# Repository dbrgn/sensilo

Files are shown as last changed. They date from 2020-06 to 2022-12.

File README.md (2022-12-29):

# sensilo

A generic BLE sensor node based on the nRF52832. Firmware written in Rust with the RTIC framework.

Current status: Obsolete, replaced by [sensilo-v2](https://github.com/dbrgn/sensilo-v2).

## Project Name

"Sensilo" is the [Esperanto word for "sensor"](https://en.bab.la/dictionary/esperanto-english/sensilo).

## Components

- [Firmware](./firmware/)
- [Gateway](./gateway/)
- [Hardware](./hardware/)

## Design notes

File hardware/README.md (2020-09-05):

# Sensilo

Sensilo sensor node PCB.

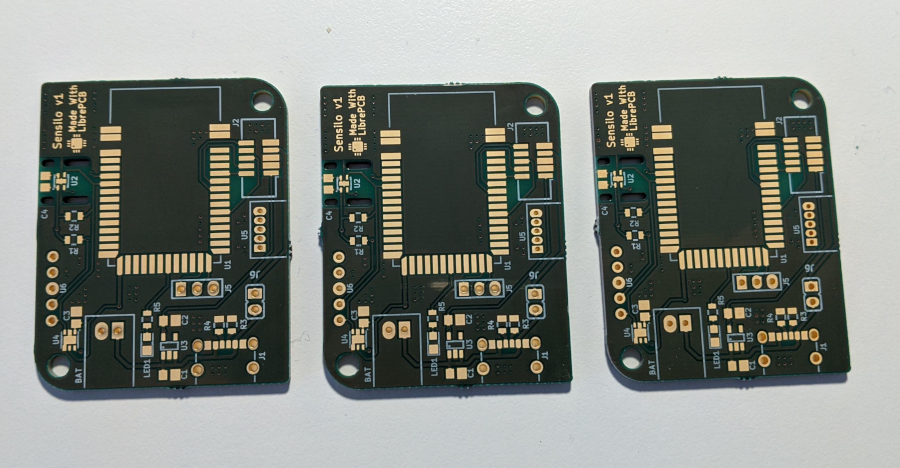
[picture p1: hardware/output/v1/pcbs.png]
PCBs


## Editing

This is a [LibrePCB](https://librepcb.org) project!

## License

© 2020 Danilo Bargen. Licensed under the TAPR Open Hardware License
(www.tapr.org/OHL).

If you make any modification to this board, it would be great if you could let
me know at mail@dbrgn.ch.

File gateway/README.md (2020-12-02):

# Sensilo Gateway

Rust daemon that receives Sensilo advertisement frames (aka beacons) via
Bluetooth (through libpcap) and processes them.

Measurements are sent to an InfluxDB server.

## Setup

Ensure that the bluetooth adapter is powered on and in scan mode:

    bluetoothctl power on
    bluetoothctl scan on

Then run the daemon with the necessary permissions.

## Config

The daemon requires a config file called `config.toml`. Example:

```toml
[influxdb]
connection_string = "https://influxdb.example.com"
user = "influxuser"
pass = "influxpass"
db = "sensilo"

[[devices]]
name = "Sensilo1"
hex_addr = "864fe067997a"
location = "Kitchen"

[[devices]]
name = "Sensilo2"
hex_addr = "864fe067997b"
```

## Logging

To see the log output:

    export RUST_LOG=sensilo_gateway=debug

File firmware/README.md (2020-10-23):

# Sensilo Node Firmware

Firmware uses the RTIC embedded concurrency framework.

## Tasks

The following tasks make up a measurement cycle:

    +----+    +-----------------+        +-------------------+
    |init| -> |start_measurement| -(t)-> |collect_measurement|
    +----+    +-----------------+        +-------------------+
                                                      |
                                                      v
                                        +----------------+
                                    +-- |broadcast_beacon|
                                    |   +----------------+
                                    |        ^    |
                                    |        |    |
                                    +--(b)---+    |
                                                  v
                                          +----------+
                                          |power_down|
                                          +----------+
Delays:

- `t`: Max measurement duration for the sensor used
- `b`: BEACON_BURST_INTERVAL_MS

## Packet Format

Data is broadcasted in an unconnectable BLE advertisement frame (aka beacon).
The advertising data contains the device name ("Sensilo") as well as a
manufacturer specific entry (Company ID `0xff`) with the actual payload.

The payload starts with a 16 bit counter (starting at 0, incremented for every
beacon burst), followed by measurement entries.

Every measurement entry starts with a single-byte type flag (e.g. `0x01` for a
temperature measurement) followed by a type-specific payload.

All multi-byte values are in little endian byte order.

## Measurement Types

| Type | Description | Value Encoding |
|---|---|---|
| 0x01 | Temperature | Millidegrees Celsius (i32) |
| 0x02 | Relative Humidity | Millipercent (i32) |
| 0x03 | Particulate Matter | TBD |
| 0x04 | Ambient Light | Lux (f32) |

## Development

### Unlocking

When receiving a new board (e.g. the E73-TBB), the nRF often needs to be
unlocked before being able to connect to it with the debugger.

Instructions: https://blog.dbrgn.ch/2020/5/16/nrf52-unprotect-flash-jlink-openocd/

### Flashing (cargo-embed)

Install cargo-embed:

    $ cargo install -f cargo-embed

Flash and reset the target:

    $ cargo embed flash --release

Flash and reset, then show RTT console:

    $ cargo embed flashrtt --release

Only show RTT console:

    $ cargo embed rtt --release

### Flashing (openocd)

Run OpenOCD:

    $ ./openocd.sh

Run the code

    $ cargo run [--release]

### Flashing (J-Link GDB Server)

Run JLinkGDBServer:

    $ ./jlinkgdbserver.sh

Run the code

    $ cargo run [--release]

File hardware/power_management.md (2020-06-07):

# Power Management

## Supply Voltage

Input voltages:

- USB: 4.8-5.2V
- Battery: 2-3V

Sensor supply voltages:

- E73/nRF52832 (SoC): 1.8-3.6V
- SHTC3 (Temp/Humi): 1.62-3.6V
- VEML7700 (Lux): 2.5–3.6V
- SPS30 (PM): 4.5-5.5V

## Non-Mobile

- Power supply 5V via USB C
- LDO for conversion to 3.3V

## Mobile

- Powered by 3V button cell (may reach 2V when empty)

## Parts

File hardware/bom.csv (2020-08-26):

name | count | digikey
Lipo Charger | 2 | 1528-4410-ND

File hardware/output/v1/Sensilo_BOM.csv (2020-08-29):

Quantity | Designators | Value | Device | Package | MANUFACTURER | PARTNUMBER | DIGIKEY
1 | BAT | S2B-XH-A | S2B-XH-A | JST_S2B-XH-A | JST | S2B-XH-A | 455-2257-ND
2 | C1, C2 | 1μF | C-0805 | C-0805 | Samsung | CL21B105KOFNNNG | 1276-6471-1-ND
2 | C3, C4 | 100nF | C-0805 | C-0805 | Samsung | CL21B104KACNNNC | 1276-1099-1-ND
1 | J1 | UJC-HP-3-SMT-TR | UJC-HP-3-SMT-TR | CUI_UJC-HP-3-SMT-TR | CUI Devices | UJC-HP-3-SMT-TR | 2223-UJC-HP-3-SMT-CT-ND
1 | J2 | SWD Connector 3220-10-0300-00 | CNC Tech 3220-10-0300 | CNCTECH_3220-10-0300-XX | CNC Tech | 3220-10-0300-00 | 1175-1629-ND
1 | J5 | UART | Soldered Wire Connector 2.54mm 1x03 ⌀1.0mm | Soldered Wire Connector 1x03 ⌀1.0mm | Sullins | PPTC031LFBN-RC | S7001-ND
1 | J6 |  | Generic Pin Header 2.54mm 1x02 ⌀1.0mm | Pin Header 2.54mm 1x02 ⌀1.0mm | Adam Tech | PH1-02-UA | 2057-PH1-02-UA-ND
1 | LED1 | R 2V 2.8mA | OSRAM LS R976-NR-1 | OSRAM CHIPLED 0805 Diffused | Osram | LS R976-NR-1 | 475-1278-1-ND
1 | R1 | 10kΩ | Resistor 2012 (0805) | RESC2012 (0805) | Yageo | RC0805JR-0710KL | 311-10KARCT-ND
1 | R2 | 10kΩ | Resistor 2012 (0805) | RESC2012 (0805) | Yageo | RC0805JR-0710KL
2 | R3, R4 | 5.1kΩ | Resistor 2012 (0805) | RESC2012 (0805) | Yageo | RC0805JR-075K1L | 311-5.1KARCT-ND
1 | R5 | 470Ω | Resistor 2012 (0805) | RESC2012 (0805) | Yageo | RC0805JR-07470RL | 311-470ARCT-ND
1 | U1 | E73-2G4M04S1B | E73-2G4M04S1B | EBYTE_E73-2G4M04S1[AB] | Ebyte | E73-2G4M04S1B
1 | U2 | SHTC3 | SHTC3 | Sensirion SHTCx | Sensirion | SHTC3 | 1649-1100-1-ND
1 | U3 | TPS7A0333PDBVR 200mA | TPS7A0333PDBVx | SOT95P280X145-5 | Texas Instruments | TPS7A0333PDBVR | 296-TPS7A0333PDBVRCT-ND
1 | U4 | SGP40 | SGP30 | SENSIRION_SGPxx | Sensirion | SGP40
1 | U5 | SPS30 (JST S5B-ZR) | SPS30 JST ZH | JST_S5B-ZR | JST | S5B-ZR(LF)(SN) | 455-1672-ND
1 | U6 | Adafruit VEML7700 Breakout (Socket strip 1x5) | Adafruit VEML7700 Breakout | Adafruit VEML7700 Breakout | Sullins | PPTC051LFBN-RC | S6103-ND

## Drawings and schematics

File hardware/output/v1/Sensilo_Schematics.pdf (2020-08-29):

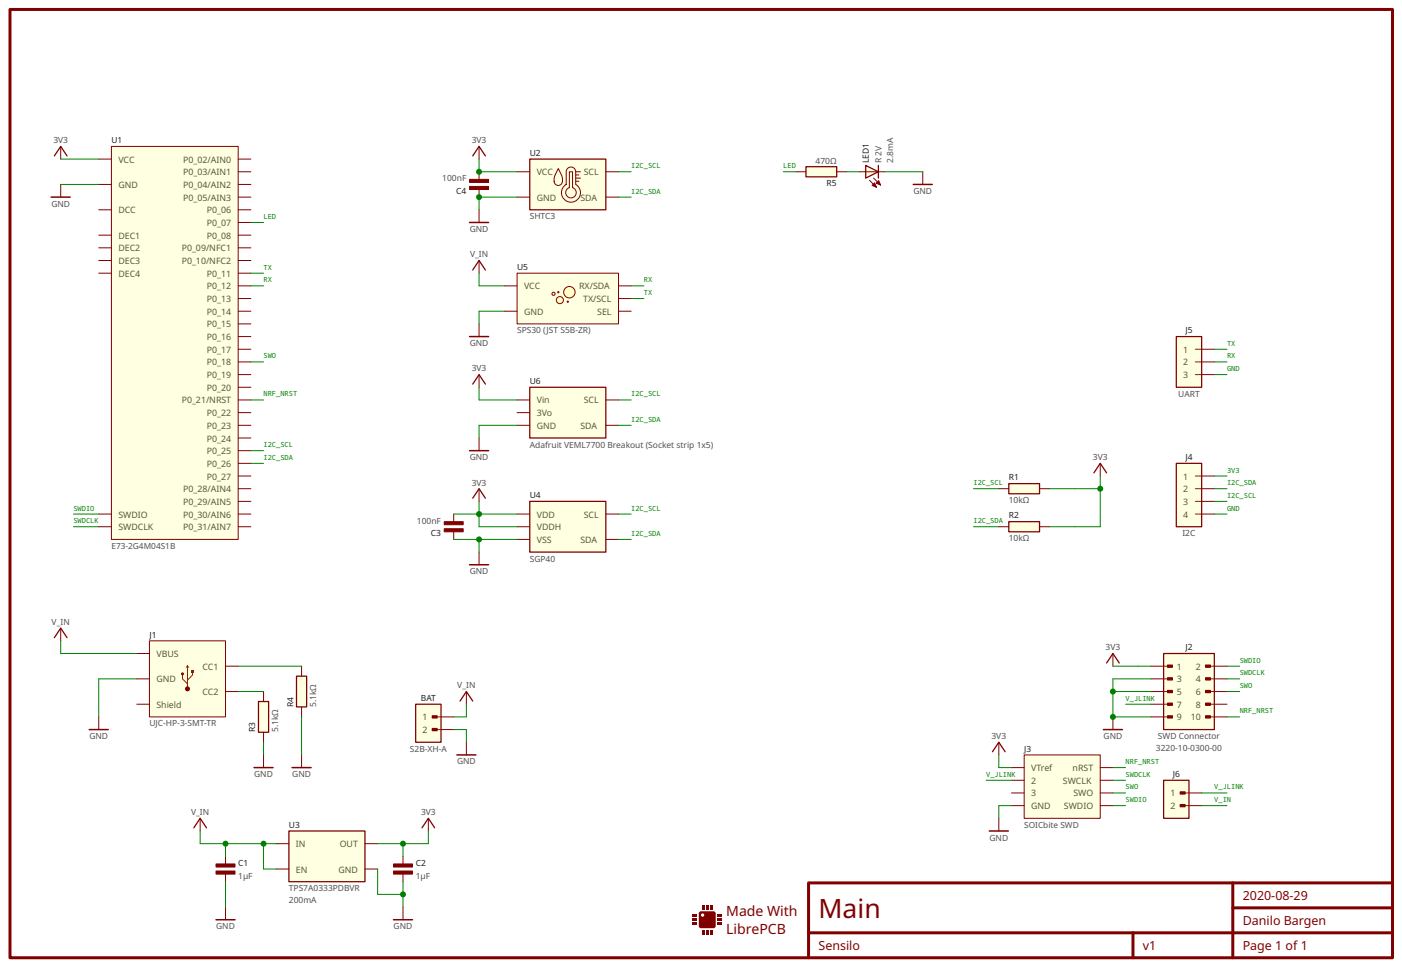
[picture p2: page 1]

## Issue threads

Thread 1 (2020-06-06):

Packet structure

dbrgn, 2020-06-06:
The current prototype simply re-broadcasts the measurements twice a second. We should have a different packet structure.

- Add a counter for deduplication
- Keep the packet type byte
- Encrypt data (?)

dbrgn, 2020-06-06:
Let's use simple type-value encoding:

    | counter | type1 | value1 | type2 | value2 | ...

- Counter: 16 bit unsigned integer, may overflow
- Type: 1 byte
- Value: Depends on type, usually fixed-size

The type and value could also be compressed (e.g. by using only 4 bits for the type), but that's probably overkill.

Closed 2020-06-06.

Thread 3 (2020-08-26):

PCB: Double-check battery connector

dbrgn, 2020-08-26:
Is the polarity correct?

Closed 2020-08-26.

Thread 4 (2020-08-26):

Hardware: Add SPS30 connector

dbrgn, 2020-08-26:

dbrgn, 2020-08-26:
Fixed!

Closed 2020-08-26.

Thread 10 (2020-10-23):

Hardware: Put VEML7700 directly on PCB

dbrgn, 2020-10-23:
https://www.digikey.ch/product-detail/de/vishay-semiconductor-opto-division/VEML7700-TR/VEML7700CT-ND/5820244

The Adafruit module adds a regulator, which isn't necessary.

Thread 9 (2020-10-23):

Hardware: Replace XH battery connector with SH

dbrgn, 2020-10-23:
The batteries I received have the wrong connector.

However, SH is better than XH, pitch is 1mm instead of 2.5mm, so they're much smaller.

dbrgn, 2020-10-23:
Replace with https://www.digikey.ch/products/de?keywords=530480210 (Molex PicoBlaze 530480210)

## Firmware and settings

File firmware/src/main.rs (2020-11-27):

#![no_main]
#![cfg_attr(not(test), no_std)]

// Panic handler
use panic_persist::get_panic_message_utf8;

use core::cmp::max;

use nrf52832_hal::{self as hal, pac, prelude::*};
use rtic::app;
use rtt_target::{rprintln, rtt_init_print};
use rubble::{
    beacon::Beacon,
    link::{ad_structure::AdStructure, DeviceAddress, MIN_PDU_BUF},
};
use rubble_nrf5x::{
    radio::{BleRadio, PacketBuffer},
    utils::get_device_address,
};
use shared_bus_rtic::SharedBus;
use shtcx::{shtc3, ShtC3};
use veml6030::Veml6030;

mod monotonic_nrf52;

use monotonic_nrf52::{Instant, U32Ext};

// Measure at a specific interval
const MEASURE_INTERVAL_MS: u32 = 3000;

// Send 5 beacons, spaced 20 ms apart
const BEACON_BURST_COUNT: u8 = 5;
const BEACON_BURST_INTERVAL_MS: u32 = 20;

// Sensor types
const SENSOR_TEMP: u8 = 0x01;
const SENSOR_HUMI: u8 = 0x02;
const SENSOR_LUX: u8 = 0x04;

// BLE Beacon
const AD_STRUCTURE_MANUFACTURER_DATA: u8 = 0xff;

// VEML sensor integration time
const VEML_INTEGRATION_TIME: veml6030::IntegrationTime = veml6030::IntegrationTime::Ms25;

pub struct SharedBusResources<T: 'static> {
    sht: ShtC3<SharedBus<T>>,
    veml: Veml6030<SharedBus<T>>,
}

type SharedBusType = hal::twim::Twim<pac::TWIM0>;

#[app(device = crate::pac, peripherals = true, monotonic = crate::monotonic_nrf52::Tim1)]
const APP: () = {
    struct Resources {
        // LED
        led: hal::gpio::p0::P0_07<hal::gpio::Output<hal::gpio::PushPull>>,

        // BLE
        #[init([0; MIN_PDU_BUF])]
        ble_tx_buf: PacketBuffer,
        #[init([0; MIN_PDU_BUF])]
        ble_rx_buf: PacketBuffer,
        radio: BleRadio,
        device_address: DeviceAddress,

        // I²C devices
        i2c: SharedBusResources<SharedBusType>,

        // Measurements
        #[init(None)]
        measurement_start: Option<Instant>,

        // Beacon
        #[init(None)]
        beacon: Option<Beacon>,
    }

    #[init(resources = [ble_tx_buf, ble_rx_buf], spawn = [start_measurement])]
    fn init(ctx: init::Context) -> init::LateResources {
        // Init RTT
        rtt_init_print!();
        rprintln!("Initializing…");

        // Check for existing crash dumps
        if let Some(msg) = get_panic_message_utf8() {
            rprintln!("Found a crash dump:\n--- START OF CRASH---\n{}\n--- END OF CRASH ---", msg.trim());
        }

        // Destructure device peripherals
        let pac::Peripherals {
            CLOCK,
            FICR,
            P0,
            RADIO,
            TIMER1,
            TWIM0,
            ..
        } = ctx.device;

        // Set up clocks. On reset, the high frequency clock is already used,
        // but we also need to switch to the external HF oscillator. This is
        // needed for Bluetooth to work.
        let _clocks = hal::clocks::Clocks::new(CLOCK).enable_ext_hfosc();

        // Set up GPIO peripheral
        let gpio = hal::gpio::p0::Parts::new(P0);

        // Initialize monotonic timer on TIMER1 (for RTIC)
        monotonic_nrf52::Tim1::initialize(TIMER1);

        // Initialize LED pin
        // TODO: LED wrapper that knows whether low power mode is enabled
        let led = gpio.p0_07.into_push_pull_output(hal::gpio::Level::High);

        // Initialize TWIM (I²C) peripheral
        let sda = gpio.p0_26.into_floating_input().degrade();
        let scl = gpio.p0_25.into_floating_input().degrade();
        let twim = hal::twim::Twim::new(
            TWIM0,
            hal::twim::Pins { sda, scl },
            hal::twim::Frequency::K250,
        );

        // Create shared bus
        let bus_manager = shared_bus_rtic::new!(twim, SharedBusType);

        // Initialize SHT sensor
        let mut sht = shtc3(bus_manager.acquire());
        rprintln!(
            "SHTC3: Device identifier is {}",
            sht.device_identifier().unwrap()
        );

        // Initialize VEML7700 lux sensor
        let mut veml = Veml6030::new(bus_manager.acquire(), veml6030::SlaveAddr::default());
        if let Err(e) = veml.set_gain(veml6030::Gain::OneQuarter) {
            rprintln!("VEML7700: Could not set gain: {:?}", e);
        }
        if let Err(e) = veml.set_integration_time(VEML_INTEGRATION_TIME) {
            rprintln!("VEML7700: Could not set gain: {:?}", e);
        }

        // Get bluetooth device address
        let device_address = get_device_address();
        rprintln!("Bluetooth device address: {:?}", device_address);

        // Initialize radio
        let radio = BleRadio::new(
            RADIO,
            &FICR,
            ctx.resources.ble_tx_buf,
            ctx.resources.ble_rx_buf,
        );

        // Schedule measurement immediately
        ctx.spawn.start_measurement().unwrap();

        rprintln!("Init done");
        init::LateResources {
            radio,
            device_address,
            i2c: SharedBusResources { sht, veml },
            led,
        }
    }

    #[idle]
    fn idle(_ctx: idle::Context) -> ! {
        // It seems that the HFCLK is stopped in standby mode (entered through WFE/WFI).
        // This prevents the monotonic timer from working. To avoid this issue, don't go into sleep
        // mode in idle, but instead do busy-looping for now.
        loop {
            cortex_m::asm::nop();
        }
    }

    /// Start a measurement
    #[task(resources = [i2c, measurement_start], schedule = [collect_measurement])]
    fn start_measurement(ctx: start_measurement::Context) {
        let i2c = ctx.resources.i2c;
        let power_mode = shtcx::PowerMode::NormalMode;

        // Store the instant when this task was scheduled.
        // This ensures that there is no jitter in scheduling.
        *ctx.resources.measurement_start = Some(ctx.scheduled);

        // Trigger SHTC3 measurement
        i2c.sht.start_measurement(power_mode).unwrap();
        let sht_delta_us: u32 = shtcx::max_measurement_duration(&i2c.sht, power_mode) as u32;

        // Turn on VEML7700
        //
        // Note: After enabling the sensor, a startup time of 4 ms plus the integration time must
        // be awaited.
        if let Err(e) = i2c.veml.enable() {
            rprintln!("VEML7700: Could not enable sensor: {:?}", e);
        }
        let veml_delta_us: u32 = VEML_INTEGRATION_TIME.as_us() + 4_000;

        // Calculate timedelta until collection
        let timedelta = max(sht_delta_us, veml_delta_us).micros();

        // Schedule measurement collection
        ctx.schedule
            .collect_measurement(Instant::now() + timedelta)
            .unwrap();
    }

    /// Collect a measurement. Then send the data using non-connectable BLE
    /// advertisement frames (beacons).
    #[task(
        resources = [i2c, measurement_start, device_address, beacon],
        schedule = [start_measurement],
        spawn = [broadcast_beacon],
    )]
    fn collect_measurement(ctx: collect_measurement::Context) {
        static mut COUNTER: u16 = 0;

        let i2c = ctx.resources.i2c;

        // Take measurement start time
        let measurement_start = ctx
            .resources
            .measurement_start
            .take()
            .expect("Cannot collect measurement without starting a measurement first");

        // Collect SHTC3 measurement result
        let sht_measurement = i2c.sht.get_measurement_result().unwrap();
        rprintln!(
            "SHTC3 measurement: {}°C / {} %RH",
            sht_measurement.temperature.as_degrees_celsius(),
            sht_measurement.humidity.as_percent()
        );

        // Collect VEML7700 measurement result
        let veml_measurement = match i2c.veml.read_lux() {
            Ok(lux) => {
                rprintln!("VEML7700 measurement: {:.1} lx", lux);
                Some(lux)
            }
            Err(e) => {
                rprintln!("VEML7700: Could not measure lux: {:?}", e);
                None
            }
        };
        if let Err(e) = i2c.veml.disable() {
            rprintln!("VEML7700: Could not shut down: {:?}", e);
        }

        // Prepare beacon payload
        let temp = sht_measurement
            .temperature
            .as_millidegrees_celsius()
            .to_le_bytes();
        let humi = sht_measurement.humidity.as_millipercent().to_le_bytes();
        let lux = veml_measurement
            .expect("TODO: Allow VEML measurement errors")
            .to_le_bytes();
        let counter_bytes = COUNTER.to_le_bytes();
        #[rustfmt::skip]
        let payload = [
            0xff, 0xff,
            counter_bytes[0], counter_bytes[1],
            SENSOR_TEMP, temp[0], temp[1], temp[2], temp[3], // i32 LE
            SENSOR_HUMI, humi[0], humi[1], humi[2], humi[3], // i32 LE
            SENSOR_LUX, lux[0], lux[1], lux[2], lux[3], // f32 LE
        ];

        // Create beacon
        let advertisement_data = [
            AdStructure::CompleteLocalName("Sensilo"),
            AdStructure::Unknown {
                ty: AD_STRUCTURE_MANUFACTURER_DATA,
                data: &payload,
            },
        ];
        let beacon = Beacon::new(*ctx.resources.device_address, &advertisement_data)
            .expect("Could not create beacon");
        *ctx.resources.beacon = Some(beacon);
        rprintln!("Created beacon with counter {}", COUNTER);

        // Broadcast beacon
        if ctx.spawn.broadcast_beacon(0).is_err() {
            rprintln!("Error: Could not spawn broadcast_beacon");
        }

        // Increment counter (allow wrap-around)
        *COUNTER = COUNTER.wrapping_add(1);

        // Schedule a new measurement
        ctx.schedule
            .start_measurement(measurement_start + MEASURE_INTERVAL_MS.millis())
            .unwrap();
    }

    /// Broadcast the beacon until the BEACON_BURST_COUNT has been reached.
    #[task(resources = [radio, beacon, led], schedule = [broadcast_beacon])]
    fn broadcast_beacon(ctx: broadcast_beacon::Context, i: u8) {
        if i == 0 {
            ctx.resources.led.set_low().ok();
        } else if i >= BEACON_BURST_COUNT {
            ctx.resources.led.set_high().ok();
            return;
        }

        if let Some(beacon) = ctx.resources.beacon {
            beacon.broadcast(ctx.resources.radio);
            rprintln!("Sent beacon");

            if ctx
                .schedule
                .broadcast_beacon(ctx.scheduled + BEACON_BURST_INTERVAL_MS.millis(), i + 1)
                .is_err()
            {
                rprintln!("Error: Could not re-schedule broadcast_beacon");
            }
        } else {
            rprintln!("Error: No beacon that can be broadcasted");
        }
    }

    // Provide unused interrupts to RTIC for its scheduling
    extern "C" {
        fn SWI0_EGU0();
        fn SWI1_EGU1();
        fn SWI2_EGU2();
        fn SWI3_EGU3();
        fn SWI4_EGU4();
        fn SWI5_EGU5();
    }
};

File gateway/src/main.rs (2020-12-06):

use std::collections::HashMap;

use futures::StreamExt;
use hci::protocol::{
    BasicDataType_Data, HciEvent_Event, HciMessage, HciMessage_Message, LeMetaEvent_Event,
};
use lru::LruCache;
use pcap_async::{Config, Handle, Packet, PacketStream};

mod config;
mod influxdb;
mod measurement;
mod types;

use measurement::MeasurementBuilder;
use types::Address;

// Store a LRU cache with the last `DEDUPLICATION_LRU_SIZE` counters for every address.
// If a counter value is contained in the cache, ignore the message.
const DEDUPLICATION_LRU_SIZE: usize = 5;
type DeduplicationCache = HashMap<Address, LruCache<u16, ()>>;

fn print_usage(args: &[String]) {
    println!("Sensilo Gateway\n");
    println!("Usage: {} [-h|--help] [CONFIGFILE]", args[0]);
}

fn main() -> anyhow::Result<()> {
    env_logger::init();

    // Parse args
    let args: Vec<String> = std::env::args().collect();
    if args.iter().any(|arg| arg == "-h" || arg == "--help") {
        print_usage(&args);
        std::process::exit(0);
    }
    if args.len() > 2 {
        print_usage(&args);
        std::process::exit(1);
    }

    println!("Sensilo Gateway\n");

    // Parse config
    let configfile = args.iter().nth(1).map(|s| &**s).unwrap_or("config.toml");
    println!("Loading config from {}...", configfile);
    let config: config::Config = toml::from_str(&std::fs::read_to_string(configfile)?)?;
    let addresses: Vec<Address> = config
        .devices
        .iter()
        .map(|dev| Address::from_hex(&dev.hex_addr))
        .collect();

    println!("Available bluetooth capture interfaces:");
    for iface in pcap_async::Info::all().expect("Could not get list of interfaces") {
        if iface.name.contains("blue") || iface.name.contains("ble") {
            println!("  - {}", iface.name);
            for ip in iface.ips {
                println!("    - {}", ip);
            }
        }
    }

    println!("Listening for beacons from the following devices:");
    for dev in &config.devices {
        if let Some(ref location) = dev.location {
            println!("  - [{}] {} ({})", dev.hex_addr, dev.name, location);
        } else {
            println!("  - [{}] {}", dev.hex_addr, dev.name);
        }
    }

    // Create HTTP client
    let agent = influxdb::make_ureq_agent();

    println!();
    smol::block_on(async {
        println!("Opening device bluetooth0...");
        let handle = Handle::live_capture("bluetooth0").expect("No handle created");
        //let handle = Handle::file_capture("/tmp/ble.pcap").expect("No handle created");

        let mut pcap_config = Config::default();
        pcap_config.with_blocking(true);

        let mut stream = PacketStream::new(pcap_config, std::sync::Arc::clone(&handle))
            .expect("Failed to build");

        let mut deduplication_cache: DeduplicationCache = HashMap::new();
        while let Some(packets_result) = stream.next().await {
            if let Ok(packets) = packets_result {
                for packet in packets {
                    log::trace!("{:?}", packet);
                    // TODO: Non-await?
                    let _ = process_packet(
                        packet,
                        &mut deduplication_cache,
                        &config,
                        &addresses,
                        agent.clone(),
                    )
                    .await;
                }
            } else {
                println!("Error: {:?}", packets_result);
            }
        }

        Ok(())
    })
}

async fn process_packet(
    packet: Packet,
    deduplication_cache: &mut DeduplicationCache,
    config: &config::Config,
    addresses: &[Address],
    agent: ureq::Agent,
) -> Option<()> {
    // Validate length
    if packet.original_length() != packet.actual_length() {
        log::debug!(
            "Invalid packet length: {} != {}",
            packet.original_length(),
            packet.actual_length()
        );
        return None;
    }

    // Try to parse HCI message
    let payload = &packet.data()[4..];
    let parsed = HciMessage::parse(payload)
        .map_err(|e| {
            log::debug!("Could not parse HCI message");
            e
        })
        .ok()?;

    if !parsed.0.is_empty() {
        log::debug!("Payload parsed incompletely");
        return None;
    }

    // Extract event
    let event = if let HciMessage_Message::HciEvent(val) = parsed.1.get_message() {
        val
    } else {
        log::trace!("Ignoring non-event message");
        return None;
    };

    // We're only interested in LE meta events
    let le_event = if let HciEvent_Event::LeMetaEvent(val) = event.get_event() {
        val
    } else {
        log::trace!("Ignoring non-LeMetaEvent event");
        return None;
    };

    // We're only interested in advertising reports
    let adv_report = if let LeMetaEvent_Event::LeAdvertisingReport(val) = le_event.get_event() {
        val
    } else {
        log::trace!("Ignoring non-LeAdvertisingReport");
        return None;
    };

    // Filter by address
    let address = Address::from_inverted_slice(&adv_report.get_address());
    if !addresses.contains(&address) {
        log::trace!("Ignoring device with address {}", address);
        return None;
    }

    // Get data
    let mut builder = MeasurementBuilder::new(address, adv_report.get_rssi());
    log::trace!("Frame: {:?}", adv_report);
    for datum in adv_report.get_data() {
        match datum.get_data() {
            BasicDataType_Data::CompleteLocalName(name) => {
                builder.local_name(name.get_local_name());
            }
            BasicDataType_Data::ManufacturerSpecificData(data) => {
                if data.get_company_identifier_code() == 0xffff {
                    let payload = data.get_data();
                    log::trace!("Payload: {:?}", payload);
                    if let Err(e) = builder.parse_payload(&payload) {
                        log::warn!("Could not parse payload: {}", e);
                    }
                } else {
                    // Not a Sensilo advertisement frame
                }
            }
            other => {
                log::debug!("Ignoring datum in advertising report: {:?}", other);
            }
        }
    }
    let measurement = builder.build().unwrap();

    // Deduplicate beacons
    let lru = deduplication_cache
        .entry(address)
        .or_insert_with(|| LruCache::new(DEDUPLICATION_LRU_SIZE));
    if lru.get(&measurement.counter).is_some() {
        log::debug!("Ignoring duplicate frame (counter {})", measurement.counter);
        return None;
    } else {
        lru.put(measurement.counter, ());
    }
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

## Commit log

2020-05-19 Add support for SHTC1 temperature measurements
2020-05-27 Switch from BLE advertisement to sending measurement beacons
2020-06-06 Firmware: Remove delay module
    Everything should be event/interrupt drivern.
2020-06-07 Hardware: Start designing power supply
2020-06-07 Hardware: Add power supply
2020-06-07 Hardware: Add reset button
2020-06-07 Hardware: Add LED
2020-06-07 Hardware: Add SWD conn and power selector jumper
2020-06-07 Hardware: Add I2C / UART headers
2020-06-08 Hardware: Connect uC to GND/VCC signals
2020-08-22 Start replacing LiFePo with LiPo battery
    - No more cutoff detection needed
    - Always use regulator
    - Replace regulator with different one
2020-08-23 Hardware: Merge USB and battery input nets
2020-08-23 Hardware: Use JST connector for battery
2020-08-23 Hardware: Add jumper for JLink power
2020-08-23 Hardware: Start working on PCB
2020-08-26 Hardware: Update board size, add mounting holes
2020-08-26 Hardware: Add text to PCB
2020-08-26 Hardware: Alter board shape
2020-08-26 Hardware: Label battery +/- (fixes #3)
2020-08-26 Hardware: Add SPS30 connector
    [bom.csv]
2020-08-26 Hardware: Fix DRC errors by splitting groundplane
2020-08-29 Hardware: Add SGP40 (with SGP30 footprint)
2020-08-29 Hardware: Update E73 footprint
2020-08-29 Generate v1
    [Sensilo_BOM.csv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]
2020-09-05 Hardware: Add photo of PCBs
2020-10-22 Firmware: Fix I²C pins
    [main.rs]
2020-10-22 Firmware: Enable LED
2020-10-23 Firmware: RTFM → RTIC
2020-10-23 Firmware: Switch from SHTC1 to SHTC3
2020-10-28 Hardware: Label UART pins (#6)
2020-10-28 Hardware: Move battery labels to placement layer (#7)
2020-10-28 Firmware: Switch branch for veml6030 driver
2020-10-28 Firmware: Switch to panic-persist
2020-11-27 Gateway: Filter devices using config
2020-12-06 Switch from async-h1 to ureq
    This gets rid of the openssl dependency and makes the HTTP client code
    much simpler (albeit blocking).
2020-12-07 Gateway: Don't print auth info
